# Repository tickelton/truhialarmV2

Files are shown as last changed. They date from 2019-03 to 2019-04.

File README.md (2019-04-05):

# truhialarmV2

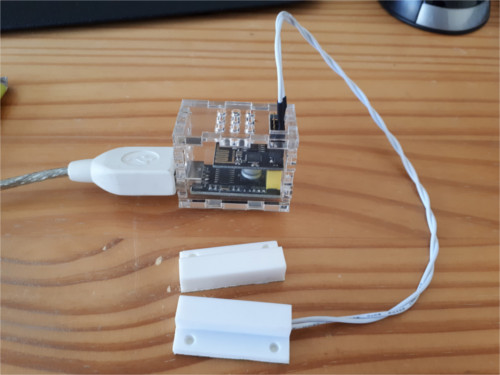
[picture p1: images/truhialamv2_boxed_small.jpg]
image of truhialarmV2


truhialarmV2 is a simple IoT project with the goal of sending email notifications when a sensor changes state.

It currently targets the ESP8266 microcontroller, in particular the ESP-01 board.

The code was written for the Arduino development environment for the ESP8266 and has no other external dependencies other than the ESP8266 package.

The particular use case this project was designed for is to monitor the lid of a chest freezer and remind me to update the list of its contents I have pinned to my fridge.

## Hardware

The project consists of only 3 pieces of hardware:

* the ESP-01 itself
* a CH340 USB to serial adapter
* a magnetic door sensor

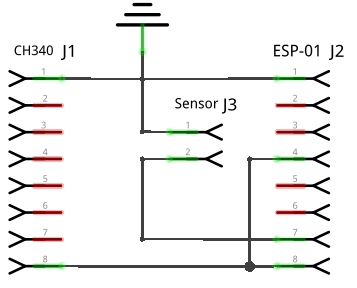
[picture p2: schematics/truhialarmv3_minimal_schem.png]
schematic


The CH340 Adapter is not actually necessary but only used as a power supply. Alternatively you can use any other type of 3.3v power supply.

I chose to stick with it for production use as it was the most convenient 3.3v power supply I had at hand and it gives me the opportunity to just plug the finished device into a computer and get diagnosis output through a serial terminal if anything need debugging.

For more elaborate debugging circuits and flashing instructions, please refer to the excellent instructions that are pretty much everywhere on the internet, e.g.:

https://www.allaboutcircuits.com/projects/breadboard-and-program-an-esp-01-circuit-with-the-arduino-ide/

http://www.arjunsk.com/iot/iot-using-esp8266-programmer-ch340g-chip-adapter/

## Software

The software is contained in a single source file to be compiled and uploaded with the Arduino IDE.

Please refer to [the above link](https://www.allaboutcircuits.com/projects/breadboard-and-program-an-esp-01-circuit-with-the-arduino-ide/) for detailed instructions.

## Sensor

The sensor is a cheap magnetic door sensor. Since the sensor just acts as a switch the project works just as well with all other kinds of sensor that behave this way, e.g. simple push button switches for breadboard use.

## Case

The case that can be seen in the image on top was laser cut from 3mm acrylic.

The SVG file to recreate the case can be found in the images directory.

## Annotations

While the ESP-01 board does have two dedicated GPIO pins, in this case the sensor is connected to neither of them but the RX pin is reconfigured to act as GPIO3 and the sensor is attached there.

The reason for this is that on the ESP-1 GPIO0 and GPIO2 are overloaded with the selection of the programming/bootloader mode.

For more details please refer to the excellent guide on the topic that can be found here:

https://www.forward.com.au/pfod/ESP8266/GPIOpins/ESP8266_01_pin_magic.html

## Copyright

truhialamV2 is licensed under the ISC license.

See LICENSE for details.

Copyright (c) 2019 tick <tickelton@gmail.com>

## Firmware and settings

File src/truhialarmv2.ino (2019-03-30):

/*
 * Copyright (c) 2019 tick <tickelton@gmail.com>
 *
 * SPDX-License-Identifier:	ISC
 */

#include <ESP8266WiFi.h>

// Types
enum lid_state {
  LID_OPEN = HIGH,
  LID_CLOSED = LOW,
};

enum pin_numbers {
  GPIO0 = 0,
  PIN_TX = 1,
  GPIO2 = 2,
  PIN_RX = 3,
};

// Constants
const uint8_t SENSOR_PIN = PIN_RX;  // Use RX pin as sensor input
const uint8_t MAIL_MAX_RETRIES = 5;
const char* const WIFI_SSID = "xxxx"; // Replace with correct SSID
const char* const WIFI_PASSWORD = "xxxx"; // Replace with WiFi password
const char* const SMTP_SERVER = "mail.example.com"; // Replace with SMTP server
const uint16_t SMTP_PORT = 25; // Replace with correct port
const uint16_t RECONNECT_INTERVAL = 10000;
const uint32_t NOTIFICATION_DELAY = 5 * 60 * 1000; // Wait 5 minutes before sending the notification
const uint16_t MAIN_LOOP_DELAY = 1000; // Run the main loop every second

// Global variables
bool sensor_irq = false;
uint8_t wifi_connection_state = 0;
WiFiClient espClient;

// Interrupt handler
void sensorEvent() {
  sensor_irq = true;
}

// Functions
uint8_t WiFiConnect()
{
  Serial.print("Connecting to ");
  Serial.println(WIFI_SSID);
  WiFi.begin(WIFI_SSID, WIFI_PASSWORD);

  for (uint8_t i = 0; i < 50; ++i) {
    if (WiFi.status() != WL_CONNECTED)
    {
      delay(200);
      Serial.print(".");
    }
  }

  Serial.println("");

  if (WiFi.status() != WL_CONNECTED) {
    Serial.println("Connection TIMEOUT");
    Serial.println("Check if access point available or SSID and Password");
    return false;
  }

  Serial.println("Connection: ESTABLISHED");
  Serial.print("Got IP address: ");
  Serial.println(WiFi.localIP());
  return true;
}

void Awaits()
{
  uint32_t ts = millis();
  while (!wifi_connection_state)
  {
    delay(50);
    if (millis() > (ts + RECONNECT_INTERVAL) && !wifi_connection_state) {
      wifi_connection_state = WiFiConnect();
      ts = millis();
    }
  }
}

byte sendEmail()
{
  if (espClient.connect(SMTP_SERVER, SMTP_PORT) == 1)
  {
    Serial.println("connected");
  }
  else
  {
    Serial.println("connection failed");
    return 0;
  }
  if (!emailResp())
    return 0;

  Serial.println("Sending EHLO");
  espClient.println("EHLO www.example.com");
  if (!emailResp())
    return 0;

  Serial.println("Sending auth login");
  espClient.println("AUTH LOGIN");
  if (!emailResp())
    return 0;

  Serial.println("Sending User");
  espClient.println("dXNlcg=="); //base64, ASCII encoded Username: 'user'
  if (!emailResp())
    return 0;

  Serial.println("Sending Password");
  espClient.println("cGFzc3dvcmQ=");  //base64, ASCII encoded Password: 'password'
  if (!emailResp())
    return 0;

  Serial.println("Sending From");
  espClient.println("MAIL From: sender@example.com"); // Sender email address
  if (!emailResp())
    return 0;

  Serial.println("Sending To");
  espClient.println("RCPT To: receiver1@example.com"); // recipient email address (envelope-to)
  espClient.println("RCPT To: receiver2@example.com"); // repeat for multiple recipients
  if (!emailResp())
    return 0;

  Serial.println("Sending DATA");
  espClient.println("DATA");
  if (!emailResp())
    return 0;

  Serial.println("Sending email");
  espClient.println("To:  <receiver1@example.com>, <receiver2@example.com>"); // sender and recipient addresses as they appear in the email
  espClient.println("From: sender@example.com");
  espClient.println("Subject: Subject text");
  espClient.println("");
  espClient.println("");
  espClient.println("Example");
  espClient.println("");
  espClient.println("Email");
  espClient.println("");
  espClient.println("Text");

  espClient.println(".");
  if (!emailResp())
    return 0;

  Serial.println("Sending QUIT");
  espClient.println("QUIT");
  if (!emailResp())
    return 0;

  espClient.stop();
  Serial.println("disconnected");
  return 1;
}

byte emailResp()
{
  byte responseCode;
  byte readByte;
  int loopCount = 0;

  // Abort if no response was received within 20 seconds.
  while (!espClient.available())
  {
    delay(1);
    loopCount++;
    if (loopCount > 20000)
    {
      espClient.stop();
      Serial.println("Timeout");
      return 0;
    }
  }

  responseCode = espClient.peek();
  while (espClient.available())
  {
    readByte = espClient.read();
    Serial.write(readByte);
  }

  if (responseCode >= '4')
  {
    return 0;
  }
  return 1;
}

void send_notification() {
  uint8_t mail_retries = 0;

  Serial.println("Sending notification.");
  wifi_connection_state = WiFiConnect();
  if (!wifi_connection_state) { // if not connected to WIFI try to (re)connect
    Awaits();
  }

  while (mail_retries < MAIL_MAX_RETRIES) {
    Serial.println("Sending email");
    if (sendEmail()) {
      break;
    }
    mail_retries++;
  }

}

void setup() {
  Serial.begin(115200, SERIAL_8N1, SERIAL_TX_ONLY);

  Serial.println("Setup start");
  delay(100);

  pinMode(SENSOR_PIN, INPUT_PULLUP);
  attachInterrupt(
    digitalPinToInterrupt(SENSOR_PIN),
    sensorEvent,
    CHANGE
  );

  Serial.println("Setup done");
}

void loop() {
  if (sensor_irq) {
    delay(100); // 100ms debounce
    if (digitalRead(SENSOR_PIN) == LID_OPEN) {
      Serial.println("Lid was opened.");
    } else {
      Serial.println("Lid was closed.");
      delay(NOTIFICATION_DELAY);
      send_notification();
    }
    sensor_irq = false;
  }

  delay(MAIN_LOOP_DELAY);
}

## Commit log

2019-03-30 Finished project with code, schematics and instructions.
    [truhialarmv3_minimal.fzz]
2019-04-05 Replaces schematic PNG with SVG
